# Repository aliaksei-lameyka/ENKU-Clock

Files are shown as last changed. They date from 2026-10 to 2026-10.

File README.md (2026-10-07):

# ENKU Clock

Open, repairable, local-first e-paper alarm clock.

ENKU Clock is a compact ambient clock built around an e-paper display, physical controls and a warm wake-light. It is designed to work without subscriptions, advertisements or a mandatory cloud service.

## Status

**Rev A hardware — PCBWay DFM / prototype review**

The Rev A electronics set contains four PCBs:

| Board | Size | Layers | Status |
|---|---:|---:|---|
| Mainboard | 88 × 48 mm | 4 | Rev A validated, prototype package submitted |
| Encoder board | 24 × 23 mm | 2 | Rev A validated |
| Snooze board | 26 × 18 mm | 2 | Rev A validated |
| Wake LED board | 78 × 8 mm | 2 | Rev A validated |

The current revision has passed native KiCad manufacturing checks with zero hard DRC violations and zero unconnected items before prototype submission.

## Rev A hardware

ENKU Clock Mainboard Rev A placement

ENKU Clock daughterboards Rev A placement

## Design goals

- local-first operation
- no subscription or mandatory cloud account
- e-paper primary display
- physical rotary control and Snooze button
- warm wake-light
- repairable distributed-board construction
- documented connectors and service access
- replaceable external modules where practical
- open hardware and firmware development

## System overview

```mermaid
flowchart LR
    USB[USB-C] --> MAIN[Mainboard<br/>ESP32-S3 + power + RTC + audio + E Ink]
    BAT[1S LiPo<br/>BAT + NTC] --> MAIN
    EINK[E Ink display] <-->|24-pin FPC| MAIN
    FL[Frontlight] <-->|6-pin FPC| MAIN
    ENC[Encoder board] <-->|5-wire harness| MAIN
    SNZ[Snooze board] <-->|3-wire harness| MAIN
    LED[Wake LED board] <-->|2-wire harness| MAIN
    SPK[Speaker] <-->|2-wire harness| MAIN
```

The distributed layout keeps user controls and lighting mechanically independent from the Mainboard, improving serviceability and enclosure freedom.

## Hardware

The system is split into four boards:

- **Mainboard** — ESP32-S3, USB-C, battery charging and power path, RTC, ambient-light sensor, audio, e-paper interface and lighting control.
- **Encoder board** — side rotary control.
- **Snooze board** — top physical Snooze control.
- **Wake LED board** — independent warm-light LED board.

### Mainboard highlights

- ESP32-S3-WROOM-1
- USB-C
- BQ24074 charger / dynamic power path
- TPS62840 3.3 V regulator
- RV-3028-C7 RTC
- VEML7700 ambient-light sensor
- MAX98357A I2S amplifier
- external E Ink booster/interface
- service connectors for distributed controls and lighting

## Repository layout

```text
hardware/
  mainboard/          Mainboard KiCad PCB and manufacturing data
  daughterboards/     Encoder, Snooze and Wake LED boards
  schematics/         Rev A schematic sources
  libraries/          Project KiCad symbols and footprints
  assembly/           BOM data
docs/
  README.md
  architecture.md
  connectors.md
  mechanical-interface.md
  manufacturing.md
  bringup.md
  release-checklist.md
  repairability.md
  status.md
.github/
  ISSUE_TEMPLATE/
  workflows/
```

## Manufacturing

Rev A is currently under PCBWay prototype DFM / sourcing review. Production files are generated from the checked KiCad sources rather than maintained as hand-edited manufacturing files.

For the Mainboard, the baseline fabrication target is:

- 4-layer FR-4
- 1.6 mm
- 1 oz outer / inner copper
- ENIG
- L2 continuous GND reference
- L3 power / utility distribution
- filled/capped via-in-pad where explicitly required for SMT assembly

See [docs/manufacturing.md](docs/manufacturing.md).

## Documentation

- [Documentation index](docs/README.md)
- [Architecture](docs/architecture.md)
- [Connectors and GPIO](docs/connectors.md)
- [Mechanical interface](docs/mechanical-interface.md)
- [External components & harness BOM](docs/external-components.md)
- [Rev A procurement plan — 5 prototypes](docs/procurement-reva.md)
- [Manufacturing](docs/manufacturing.md)
- [Rev A bring-up checklist](docs/bringup.md)
- [Release checklist](docs/release-checklist.md)
- [Repairability](docs/repairability.md)
- [Project status](docs/status.md)

## Repairability

ENKU Clock uses separate boards for controls and lighting so service parts can be replaced independently. Connectors, polarity and functional interfaces are documented wherever practical.

See [docs/repairability.md](docs/repairability.md).

## Firmware

Firmware will live in this repository as the Rev A bring-up stabilizes. The first firmware milestone is a hardware bring-up image covering power, USB, RTC, ambient-light sensing, controls, audio, E Ink and lighting.

## Project stage

This is prototype hardware. Files may still change after DFM review and physical Rev A validation.

## License

The project is intended to be open source. Final hardware/firmware license files will be added before the first tagged public release.

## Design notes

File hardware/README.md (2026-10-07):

# Hardware

This directory contains the canonical ENKU Clock Rev A hardware source.

- `mainboard/` — 4-layer Mainboard PCB
- `daughterboards/` — Encoder, Snooze and Wake LED PCBs
- `schematics/` — hierarchical Rev A schematic sheets
- `libraries/` — project-specific KiCad libraries
- `assembly/` — assembly BOM data
- `footprint-plan.csv` — footprint planning reference

Generated Gerbers and production archives are release artifacts, not hand-maintained source files.

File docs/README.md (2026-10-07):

# ENKU Clock documentation

Start here if you are looking for a specific part of the project.

| Topic | Document |
|---|---|
| System overview | [Architecture](architecture.md) |
| GPIO and connectors | [Connectors and GPIO](connectors.md) |
| Mechanical interface | [Mechanical interface](mechanical-interface.md) |
| External parts / harnesses | [External components](external-components.md) |
| 5-unit Rev A shopping / preparation list | [Procurement plan](procurement-reva.md) |
| Fabrication / assembly | [Manufacturing](manufacturing.md) |
| First power-up | [Rev A bring-up](bringup.md) |
| Release gates | [Release checklist](release-checklist.md) |
| Service philosophy | [Repairability](repairability.md) |
| Current project state | [Status](status.md) |

## Rev A state

Rev A is a prototype revision currently in fabricator DFM / sourcing review. CAD validation is complete for the submitted source state; physical validation begins when assembled hardware arrives.

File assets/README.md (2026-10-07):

# Visual assets

Generated placement maps are derived from the current Rev A KiCad board coordinates. They are documentation aids, not substitutes for Gerber/DFM review.

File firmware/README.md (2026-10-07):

# Firmware

ENKU Clock firmware will be added here as Rev A hardware bring-up begins.

Planned first-stage bring-up covers power, USB, RTC, ambient-light sensing, audio, E Ink, physical controls and wake-light control.

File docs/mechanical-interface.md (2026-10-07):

# Mechanical interface

## Mainboard coordinate convention

For Rev A mechanical review:

- y = 0 mm — rear enclosure wall
- y = 48 mm — front / display side
- x = 0 mm — left side
- x = 88 mm — right side

## USB-C

The current USB-C connector is located near the rear-right area of the Mainboard and opens toward the rear wall.

The enclosure must provide:

- plug overmold clearance;
- insertion/removal clearance;
- no rib loading the connector shell;
- no standoff collision with shell anchors.

## ESP32 antenna

The antenna volume must remain free of:

- copper outside the module design intent;
- battery;
- speaker magnet;
- cable bundles;
- metal fasteners or enclosure metal.

The enclosure above the antenna should remain plastic.

## User controls

User-facing controls are mechanically carried by daughterboards:

- Encoder board — right wall
- Snooze board — below top key
- Wake LED board — bottom diffuser channel

The Mainboard should not carry encoder shaft or Snooze-button mechanical loads.

## Display and frontlight

E Ink and frontlight FPCs connect directly to the Mainboard.

Mechanical design should allow:

- acceptable bend radius;
- connector access during service;
- display/FPC disconnection before Mainboard removal.

## Service objective

Battery, speaker, Encoder board, Snooze board, Wake LED board, display and Mainboard should be individually replaceable without cutting wires or desoldering another mechanical module.

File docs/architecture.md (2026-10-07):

# Architecture

ENKU Clock Rev A uses a distributed-board architecture.

## Mainboard

The Mainboard contains the system controller and shared power / peripheral functions:

- ESP32-S3-WROOM-1
- USB-C
- battery charging and dynamic power path
- 3.3 V system regulator
- RTC
- ambient-light sensor
- I2S audio amplifier
- E Ink interface and external booster network
- frontlight / wake-light control
- service and daughterboard connectors

The board outline is 88 × 48 mm and uses four copper layers.

## Daughterboards

### Encoder board

A small side-mounted board carrying the physical rotary control interface.

### Snooze board

A dedicated top-button board so the Snooze control can be positioned independently from the Mainboard.

### Wake LED board

A long narrow lighting board used for the warm wake-light. Keeping it separate allows the optical and mechanical design to evolve without redesigning the Mainboard.

## Design principles

The distributed architecture is deliberate:

- controls can be replaced independently;
- connectors can be documented and serviced;
- mechanical placement is not tied to one large rigid PCB;
- lighting can be iterated separately;
- the Mainboard remains accessible for repair and debugging.

## Revision policy

Rev A is the first physical prototype revision. Electrical and mechanical changes after prototype bring-up will be captured as a new revision rather than silently changing released manufacturing data.

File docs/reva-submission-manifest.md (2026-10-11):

# ENKU Clock Rev A — PCBWay submission manifest

This bundle is the authoritative **prototype submission package** for the source commit recorded at the bottom of the generated copy.

## Order split

| Folder | Board | Manufacturing route | Prototype qty | PCB spec |
|---|---|---|---:|---|
| `01-mainboard-PCBA` | Mainboard | PCBWay PCB + SMT assembly | 5 | 88 × 48 mm, 4-layer, 1.6 mm, ENIG, 1 oz outer/inner |
| `02-encoder-PCBA` | Encoder | PCBWay PCB + SMT assembly | 5 | 24 × 23 mm, 2-layer, 1.6 mm, ENIG |
| `03-snooze-PCBA` | Snooze | PCBWay PCB + SMT assembly | 5 | 26 × 18 mm, 2-layer, 1.6 mm, ENIG |
| `04-wake-led-BARE-PCB` | Wake LED | **Bare PCB only; local assembly** | 5 minimum | 78 × 8 mm, 2-layer, 1.0 mm, ENIG |

If PCBWay's price difference is negligible, ordering 10 bare Wake LED PCBs is acceptable for prototype spares, but the required functional set is five.

## What to upload to PCBWay

### Mainboard

Upload:
- `mainboard-reva-PCBWay-Gerbers.zip`
- `mainboard-reva-bom.csv`
- `mainboard-reva-cpl.csv`

Request **5 assembled boards**, top-side SMT assembly.

This submission **replaces** the old Mainboard inquiry/order package. Do not pay the old quotation without replacing its files and receiving a new sourcing review.

### Encoder

Upload:
- `encoder-board-reva-PCBWay-Gerbers.zip`
- `encoder-board-reva-bom.csv`
- `encoder-board-reva-cpl.csv`

Request **5 assembled boards**.

### Snooze

Upload:
- `snooze-board-reva-PCBWay-Gerbers.zip`
- `snooze-board-reva-bom.csv`
- `snooze-board-reva-cpl.csv`

Request **5 assembled boards**.

### Wake LED

Upload **only**:
- `wake-led-board-reva-BARE-PCB-Gerbers.zip`

Order as **bare PCB, no PCBWay assembly**.

The exact Nichia LEDs are sourced separately and assembled locally. The `local-assembly/` directory contains the BOM, CPL and top-paste Gerber for local stencil/reflow work.

## Mandatory sourcing instructions for PCBWay

PCBWay must provide the new **Actual Purchase Mfg Part #** list before payment.

Critical locks:

- J5: Molex **54550-2472**, 24-pin 0.5 mm TOP-CONTACT. No arbitrary substitute.
- J6 production target: Molex **54550-0672**. Rev A prototype alternate explicitly allowed: genuine Molex **54550-0671**. If neither genuine part is available, **DNP J6** and hand-fit locally.
- U5: Vishay **VEML7700-TR**. Do not silently substitute VEML7700-TT or an unverified -TR1 order code.
- Q_FL / Q2: AOS **AO3400A**. Any suffix/equivalent requires engineering approval.
- J8: JST **SM02B-GHS-TB(LF)(SN)**.
- U6 MAX98357A no longer requires a via-in-pad fill/cap process; the thermal pad exits to an adjacent normal GND via.

See `PCBWAY-SOURCING-GATES.md` for the complete sourcing audit.

## Wake LED local assembly

Exact Rev A LED:
**Nichia NFSW757GT-V3 sm275/P11d21-P12d22/K22-L12/R8000**, 2700 K, CRI80.

For five clocks:
- fitted: 30 LEDs;
- buy: **40 LEDs from one lot**;
- 10 remain as same-bin spares.

Polarity:
- pad 1 = cathode / K / WAKE_LED_RETURN;
- pad 2 = anode / A / resistor / +3V3.

Use controlled solder-paste deposition and a single reflow pass.

## Pre-payment gate

Before paying PCBWay:

1. DFM accepted for all three PCBA boards and the bare Wake LED PCB.
2. PCBWay returns the **new** Mainboard/Encoder/Snooze sourcing list against these exact BOMs.
3. Every substitution is compared against `PCBWAY-SOURCING-GATES.md`.
4. J6 is either exact 54550-0672, approved genuine 54550-0671, or explicitly DNP.
5. No Wake LED PCBA assembly is included in the PCBWay order.
6. Gerber/BOM/CPL files all come from the same generated submission bundle.

## Bring-up note

Physical panel fit remains part of prototype bring-up. The GDEY037T03-FL21 FPC contact-side geometry and the selected Molex 54550-series top-contact connector geometry have been audited and are no longer considered a PCB-release blocker.

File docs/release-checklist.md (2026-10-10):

# Release checklist

A hardware release is considered manufacturing-ready only when the checked source revision and generated manufacturing package agree.

## Source

- [x] Mainboard PCB source present
- [x] Encoder PCB source present
- [x] Snooze PCB source present
- [x] Wake LED PCB source present
- [x] project-specific footprints included
- [x] schematic sheets included
- [x] assembly BOM data included

## Rev A validation before first prototype

- [x] Mainboard native KiCad hard DRC passed
- [x] Mainboard unconnected count reached zero
- [x] Mainboard final production export passed
- [x] four copper layers exported
- [x] front and back solder mask exported
- [x] board outline and drill exported
- [x] BOM / CPL reference cross-check passed
- [x] daughterboard production artifacts generated
- [ ] current audited prototype package submitted for fabricator review
  - Previous PCBWay upload predates the final SI1308EDL, BQ24074, USB-C, EPD BOM and remote-input conditioning corrections and must be replaced before payment.

## Still required before calling Rev A physically validated

- [ ] fabricator DFM accepted
- [ ] exact sourced parts accepted
- [ ] assembled prototype received
- [ ] visual assembly inspection
- [ ] power bring-up completed
- [ ] USB validated
- [ ] RTC and ALS validated
- [ ] controls validated
- [ ] audio validated
- [ ] wake light validated
- [ ] frontlight validated
- [ ] E Ink validated
- [ ] sleep current measured
- [ ] enclosure fit verified
- [ ] Rev A issue log reviewed

## Release policy

Generated Gerbers, drill files, CPL and release ZIPs must come from a known source revision. Do not hand-edit generated fabrication output and then treat it as canonical source.

## Current audited manufacturing snapshot

Current green release-candidate source: **ed9ddd1** (`fix(bom): lock Rev A sourcing-critical part numbers`). Hardware geometry baseline: **1c3d2e55**.

- Mainboard source DRC: **0 violations / 0 unconnected**
- Daughterboards: **0 violations / 0 unconnected**
- Mainboard BOM ↔ CPL: **78 / 78 references, no missing or extra refs**
- Mainboard ↔ daughterboard harness audit: Encoder **5/5**, Snooze **3/3**, Wake LED **2/2** pin meanings match exactly for straight-through cables.
- Remote controls now have populated 10 kΩ external pull-ups on ENC_A / ENC_B / ENC_SW / SNOOZE_SW; Snooze also has a populated 10 nF hardware filter. Encoder RC capacitors remain omitted and debounce stays in firmware.
- USB-C J1 is now oriented with its mating face at the board edge; no J1 via-in-pad remains.
- U6 MAX98357A via-in-pad has been eliminated. The exposed pad remains on solid top-layer GND copper and exits to a normal adjacent GND through-via outside the thermal pad, so no special filled/capped via-in-pad process is required for U6.
- J5/J6 are locked to Molex 54550-2472 / 54550-0672 TOP-CONTACT parts. Exact GDEY037T03-FL21 front/back product imagery shows exposed gold contacts on the display-front side for both 24-pin and 6-pin tails, with black stiffeners on the reverse. With the intended fold toward the Mainboard F.Cu side this mates correctly to the Molex upper-contact geometry. The Molex recommended PCB pattern also matches the current footprints. Physical sample fit remains a bring-up check, not a PCB-release blocker.
- Exact GDEY037T03-FL21 reference-circuit audit: MBR0530 diode class, SI1308EDL MOSFET class, 10 uH / 3.0 x 3.0 x 1.5 mm EPD inductor class, and >=25 V X5R/X7R HV capacitor requirements are matched. Current HV capacitors are 50 V.
- L_EPD is now locked to Wurth 74438335100 (10 uH, 3.0 x 3.0 x 1.5 mm, 1.25 A rated, 2 A saturation class) with the manufacturer land pattern embedded in the PCB.
- GDEY037T03-FL21 / UC8253 BUSY is active-low during controller activity; firmware bring-up must use this polarity.
- Wake LED D1-D6 electrical polarity is pad 2 = anode / resistor / +3V3, pad 1 = cathode / WAKE_LED_RETURN. The cathode silkscreen marker is corrected and the accidental one-off D3 backside mask opening is removed.
- PCBWay sourcing gates are tracked in `docs/pcbway-sourcing-reva.md`: J6 has a genuine 54550-0671 Rev A fallback / DNP path; Wake LEDs are locked to stocked Nichia NFSW757GT-V3 R8000 2700 K (LEDRise SKU 33465) for local fit; VEML7700 is locked to -TR; AO3400A substitutions require explicit approval.
- Do not pay or release the existing PCBWay Mainboard order until the Gerber, BOM and CPL are replaced by the current audited set and PCBWay re-runs DFM/assembly review.

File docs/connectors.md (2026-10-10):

# Connectors and GPIO

This document captures the Rev A service interfaces and MCU ownership used by the current hardware.

## Internal architecture

The Clock is built around one Mainboard and three daughterboards:

| Interface | Remote module / load | Signals |
|---|---|---|
| Encoder | Encoder board | GND, ENC_A, ENC_B, ENC_SW, GND |
| Snooze | Snooze board | GND, SNOOZE_SW, GND |
| Wake light | Wake LED board | LED+, LED_RETURN_PWM |
| Battery | 1S LiPo pack | BAT+, BAT-, NTC |
| Speaker | speaker | SPK+, SPK- |
| E Ink | display FPC | 24-pin display interface |
| Frontlight | display/frontlight FPC | 6-pin frontlight interface |

Connector reference designators and final mating-part details should be verified against the physical Rev A assembly before a service manual is frozen.

## Encoder connector

Recommended logical order:

1. GND
2. ENC_A
3. ENC_B
4. ENC_SW
5. GND

Grounds on both cable edges are intentional. Rev A populates 10 kΩ external pull-ups on ENC_A / ENC_B / ENC_SW. Firmware should still debounce the mechanical encoder in software; no encoder RC capacitors are populated.

## Snooze connector

1. GND
2. SNOOZE_SW
3. GND

The dual-ground arrangement is intentional. Rev A populates a 10 kΩ external pull-up and 10 nF shunt capacitor on SNOOZE_SW, giving a 100 µs hardware RC time constant for EMI suppression and clean wake-state bias.

## Wake-light connector

1. LED+
2. LED_RETURN_PWM

PWM/current switching remains on the Mainboard.

## Battery connector

1. BAT+
2. BAT-
3. NTC

The target battery is a protected 1S LiPo with an integrated NTC where practical.

## Speaker connector

1. SPK+
2. SPK-

A short twisted pair is preferred if the final harness length requires it.

## USB

ESP32-S3 native USB is reserved for:

| Function | GPIO |
|---|---:|
| USB D- | GPIO19 |
| USB D+ | GPIO20 |

GPIO19/20 are not shared with other functions.

## Rev A GPIO map

### Wake and user input

| Function | GPIO |
|---|---:|
| BAT_ADC | GPIO1 |
| RTC_INT | GPIO4 |
| SNOOZE_SW | GPIO5 |
| ENC_A | GPIO6 |
| ENC_B | GPIO7 |
| ENC_SW | GPIO8 |

GPIO0 and GPIO3 are deliberately avoided for user controls because of strapping roles. GPIO2 is currently unallocated; the former BAT_ADC_EN function was removed because the battery divider is intentionally always-on.

### I2C

| Function | GPIO |
|---|---:|
| I2C_SDA | GPIO9 |
| I2C_SCL | GPIO10 |

Current shared devices include the RTC and ambient-light sensor.

### E Ink

| Function | GPIO |
|---|---:|
| EPD_SCK | GPIO11 |
| EPD_MOSI | GPIO12 |
| EPD_CS | GPIO13 |
| EPD_DC | GPIO14 |
| EPD_RST | GPIO15 |
| EPD_BUSY | GPIO16 |

### Lighting

| Function | GPIO |
|---|---:|
| WAKE_LED_PWM | GPIO17 |
| FRONTLIGHT_PWM | GPIO18 |

### Audio

| Function | GPIO |
|---|---:|
| I2S_BCLK | GPIO35 |
| I2S_LRCLK | GPIO36 |
| I2S_DOUT | GPIO37 |
| AMP_SD | GPIO38 |

### Charger / power status

| Function | GPIO |
|---|---:|
| CHG_STATUS | GPIO47 |
| POWER_GOOD | GPIO48 |

## Debug interfaces

The Rev A map preserves:

- GPIO39–42 for JTAG/debug
- GPIO43/44 for UART0
- BOOT access on GPIO0
- EN / CHIP_PU reset access

## Wake behavior

Mandatory deep-sleep wake sources:

- RTC_INT
- SNOOZE_SW

Optional:

- ENC_SW

Quadrature rotation itself is not required to wake the device in the first firmware revision.

## Harness rules

- no harness across the ESP32 antenna volume;
- no harness through the encoder shaft sweep;
- speaker wiring should stay away from the encoder bundle where practical;
- wake-light PWM return should not share a long thin return path with encoder signals;
- battery wiring should remain short and mechanically protected.

## Pre-production contact-side gate

- J5 uses Molex 54550-2472. Molex classifies 54550-series **72** tape-pack variants as right-angle ZIF **top-contact** connectors. Exact FL21 front/back product imagery shows the 24-pin tail contacts on the display-front side and a stiffener on the reverse; the intended fold toward the Mainboard leaves the contacts on the upper side for J5.
- J6 uses Molex 54550-0672, likewise a **top-contact** 0.5 mm ZIF connector. Exact FL21 product imagery shows the 6-pin frontlight tail has the same front-side exposed-contact / reverse-side stiffener arrangement. The Molex drawing explicitly places the contact point on the upper side of the inserted FPC, matching the intended fold. Do not approve an arbitrary substitute; replacement must preserve contact side, 0.5 mm pitch, pin count, pad pattern, insertion direction, actuator envelope, and mating FPC thickness.
- If the production display/frontlight FPC presents contacts on the opposite side, change the connector family or mechanical orientation before PCB release; do not solve this by flipping logical pin numbering.

## Straight-through harness audit

The current Rev A PCB sources were compared pin-by-pin. The internal harnesses are intentionally straight-through and the logical meaning of each pin matches at both board ends:

| Harness | Mainboard | Daughterboard | Result |
|---|---|---|---|
| Encoder | J3: 1 GND, 2 ENC_A, 3 ENC_B, 4 ENC_SW, 5 GND | J1: same order | PASS |
| Snooze | J4: 1 GND, 2 SNOOZE_SW, 3 GND | J1: same order | PASS |
| Wake LED | J8: 1 +3V3, 2 WAKE_LED_RETURN | J1: same order | PASS |

Do not use a cable assembly that reverses conductor order end-to-end. Pin numbering, not visual wire position, is authoritative.

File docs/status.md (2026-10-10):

# Project status

## Rev A

**Hardware:** an earlier prototype package was submitted for DFM / assembly review, but the audited Mainboard source has since advanced. The current package must replace the earlier PCBWay upload before payment.

### Mainboard

- PCB source: complete for Rev A submission
- native KiCad hard DRC: pass
- unconnected items: 0 at final production gate
- four-layer fabrication package: generated successfully
- BOM / CPL cross-check: pass, **78 / 78 references**
- daughterboard harness map: pass, straight-through pin meanings match for Encoder / Snooze / Wake LED
- remote controls: 10 kΩ external pull-ups populated on encoder A/B/SW and Snooze; Snooze also has 10 nF hardware filtering
- MAX98357A exposed-pad via-in-pad removed; EP exits to adjacent GND via outside the pad
- sourcing BOM locked for VEML7700-TR, AO3400A and exact JST/Molex connector MPNs
- physical bring-up: pending fabricated hardware

### Encoder board

- Rev A PCB source complete
- fabrication / assembly package submitted
- physical validation pending

### Snooze board

- Rev A PCB source complete
- fabrication / assembly package submitted
- physical validation pending

### Wake LED board

- Rev A PCB source complete
- LED cathode assembly marker corrected; accidental one-off backside mask opening removed
- current source supersedes the previously submitted fabrication / assembly package and must be re-exported before manufacture
- exact Nichia NFSW757G-V3 2700 K sourcing remains open because PCBWay reported it out of stock
- physical validation pending

## Next milestones

1. Fabricator DFM / sourcing review
2. Rev A fabrication and assembly
3. Power-rail and USB bring-up
4. RTC / sensor / audio validation
5. E Ink power and waveform bring-up
6. Daughterboard validation
7. Wake-light optical test
8. Rev A issue log
9. Rev B decision

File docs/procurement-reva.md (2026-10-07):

# Rev A procurement list — 5 prototype Clocks

Scope: parts and materials required to turn the PCBWay Rev A board set into **five complete ENKU Clock prototypes**.

Planning rule:
- five complete units are the build target;
- buy or prepare **one practical spare** for fragile / failure-prone / supplier-dependent external parts;
- board-side PCBA parts are excluded because they are handled in the PCBWay assembly orders.

## 1. External electronic parts

| Item | Per Clock | Build qty (5) | Recommended order qty | Status | Notes |
|---|---:|---:|---:|---|---|
| Good Display GDEY037T03-FL21, warm frontlight | 1 | 5 | **6** | ORDER | One spare display for FPC/mechanical/bring-up risk |
| PUI Audio AS04004PR-R, 4 Ω / 3 W | 1 | 5 | **6** | ORDER | One spare for acoustic/mechanical testing |
| Protected 605080 3000 mAh 1S LiPo + 10 kΩ NTC | 1 | 5 | **6** | ORDER / VERIFY | Prefer 3-wire JST-PH 2.0 terminated pack |
| Encoder harness, JST-GH 5p | 1 | 5 | **6** | MAKE / ORDER | 70–100 mm target; final length from enclosure |
| Snooze harness, JST-GH 3p | 1 | 5 | **6** | MAKE / ORDER | 60–90 mm target |
| Wake LED harness, JST-GH 2p | 1 | 5 | **6** | MAKE / ORDER | 40–70 mm target |
| Speaker harness, JST-PH 2p | 1 | 5 | **6** | MAKE / ORDER | 60–120 mm target |
| Battery harness, JST-PH 3p | 1 | 5 | **6** | MAY COME WITH BATTERY | Avoid duplicate if battery supplier terminates pack |

### Display purchasing note

Order the **frontlight version** of GDEY037T03-FL21 and explicitly request:
- warm-white frontlight;
- confirmation of frontlight CCT / available warm bin;
- 24-pin FPC contact orientation;
- 6-pin frontlight FPC contact orientation and conductor order.

Do not substitute a non-frontlight GDEY037T03 variant.

## 2. Connector housings and contacts

If harnesses are not purchased pre-crimped, procure:

| Part | Use | Needed contacts/housings for 5 | Recommended order qty |
|---|---|---:|---:|
| JST GHR-05V-S | Encoder harness housing | 5 | **6 housings** |
| JST GHR-03V-S | Snooze harness housing | 5 | **6 housings** |
| JST GHR-02V-S | Wake LED harness housing | 5 | **6 housings** |
| JST PHR-2 | Speaker harness housing | 5 | **6 housings** |
| JST PHR-3 | Battery harness housing | 5 | **6 housings** |
| JST SSHL-002T-P0.2 | GH crimp contacts | 50 total contacts for 5 systems if both ends are crimped | **60–70 contacts** |
| JST SPH-002T-P0.5S | PH crimp contacts | 25 total contacts for 5 systems if both ends are crimped | **30–40 contacts** |

Contact counts depend on whether the remote side is terminated directly to the part, uses a board-side GH/PH connector, or arrives as a vendor harness. Prefer pre-crimped leads for the Rev A build if a reliable source is available.

## 3. 3D-printed parts

| Printed part | Per Clock | Build qty | Recommended print qty | Status |
|---|---:|---:|---:|---|
| Main enclosure set | 1 | 5 | **5 + one service/test shell as needed** | CAD / PRINT |
| Encoder knob | 1 | 5 | **7** | PRINT | Two extra because fit/tolerance tuning is likely |
| Snooze key / cap | 1 | 5 | **7** | PRINT / TUNE | Two extra for travel/feel experiments |
| Internal supports / brackets | as CAD | 5 sets | **5 sets + test pieces** | CAD / PRINT |
| Wake-light diffuser carrier | 1 | 5 | **6** | CAD / PRINT | Diffuser material itself listed separately |

### Encoder knob

The knob is an ENKU-designed **3D-printed part**.

Rev A fit gate:
- shaft fit on ALPS EC11E15244G1;
- no wobble;
- no rubbing against side wall;
- enough pull-off resistance for normal use;
- still removable for service.

Print at least two extra knobs in the first tolerance run.

## 4. Optical / acoustic / mechanical consumables

| Item | Per Clock | Build qty | Recommended order qty | Status |
|---|---:|---:|---:|---|
| Wake-light diffuser material | 1 cut piece | 5 | material for **8–10 pieces** | SELECT |
| Speaker acoustic gasket / foam | 1 | 5 | **6–10** | SELECT |
| Display perimeter foam / protective gasket | 1 | 5 | **6** | SELECT |
| Battery retention foam / removable pad | as needed | 5 | one sheet / roll | SELECT |
| Cable retention clips / printed channels | as CAD | 5 sets | print with enclosure | CAD |

No permanent adhesive should make the battery non-serviceable.

## 5. Fasteners

Exact screw lengths remain dependent on enclosure CAD, but plan around the existing M2 board mounting strategy.

Prototype stock to have on hand:

| Fastener | Suggested prototype stock |
|---|---:|
| M2 machine screws, short lengths around 4/6/8 mm | **20–30 each useful length** |
| M2 washers | **30** |
| M2 nuts | **20** |
| M2 heat-set inserts, if used after shell testing | **20–30** |

Do not bulk-order final screws until enclosure wall/standoff dimensions are frozen.

## 6. Already covered by PCBWay PCBA

Do **not** buy these separately for the five prototype units unless PCBWay flags sourcing problems:

- ESP32-S3 module;
- BQ24074;
- TPS62840;
- RV-3028-C7;
- VEML7700;
- MAX98357A;
- USB-C and USB ESD;
- all Mainboard passives / E Ink booster parts;
- board-side JST/FPC connectors;
- Encoder EC11E15244G1;
- Snooze KSC221GLFS;
- six Nichia 2700 K LEDs per Wake LED board;
- Wake LED resistors;
- all four fabricated/assembled PCB types.

PCBWay sourcing must still be reviewed before payment because the Mainboard BOM may require exact-MPN clarification.

## 7. Bench / bring-up items

Not product BOM, but required to validate Rev A efficiently:

- USB-C data/power cable known to support data;
- current-limited bench supply;
- USB power meter;
- multimeter;
- oscilloscope / logic analyzer where available;
- fine probes / grabbers;
- spare mating JST leads;
- ESD-safe tweezers;
- Kapton tape;
- flux and fine solder for rework;
- small-gauge silicone wire;
- heat-shrink assortment.

## 8. Buy-now vs wait

### Safe to source now

- **6 × GDEY037T03-FL21 warm-frontlight displays**, after supplier confirms exact frontlight option;
- **6 × AS04004PR-R speakers**;
- **6 × 605080-class batteries** only if connector polarity, 10 kΩ NTC and pack dimensions are confirmed;
- small quantities of JST housings/contacts or pre-crimped leads;
- general M2 prototype hardware.

### Wait for enclosure CAD / PCBWay audit

- final harness lengths;
- production battery wire length;
- final fastener lengths;
- diffuser geometry/material cut dimensions;
- enclosure production quantity;
- any PCB parts PCBWay asks to substitute.

## 9. Minimum Rev A completeness check

Before calling one prototype mechanically complete, one full unit must have:

- [ ] Mainboard
- [ ] Encoder board
- [ ] Snooze board
- [ ] Wake LED board
- [ ] GDEY037T03-FL21 warm-frontlight display
- [ ] AS04004PR-R speaker
- [ ] 605080-class battery with NTC
- [ ] all five internal harnesses / mating connections
- [ ] printed enclosure
- [ ] printed encoder knob
- [ ] printed Snooze key
- [ ] wake-light diffuser
- [ ] service fasteners

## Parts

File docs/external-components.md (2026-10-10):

# External components — Rev A prototype

This list covers parts required for a complete ENKU Clock prototype that are **not part of the assembled PCB BOM**.

## Status legend

- **LOCK** — selected for Rev A prototype
- **LOCK / VERIFY** — selected, but physical sample or supplier detail must be verified before production
- **OPEN** — still needs final mechanical/supplier decision

## Core external parts

| Function | Selected part / target | Status | Notes |
|---|---|---|---|
| E Ink display + frontlight | Good Display **GDEY037T03-FL21** | LOCK / VERIFY | 3.7", 416×240, UC8253, 24-pin 0.5 mm E Ink FPC + bonded 6-pin frontlight FPC |
| Display frontlight color | Warm white | LOCK / VERIFY | Specify warm-white option in supplier RFQ; confirm exact CCT/bin on sample |
| Speaker | PUI Audio **AS04004PR-R** | LOCK / VERIFY | 40 mm round, 4 Ω, 3 W rated, 4 W max; acoustic/enclosure test required |
| Battery prototype | YDL **605080 3000 mAh** or equivalent custom pack | LOCK / VERIFY | Protected 1S LiPo, target 3-wire JST-PH 2.0 with 10 kΩ NTC |
| Enclosure | ENKU Clock printed enclosure | OPEN | Final Rev A CAD / fit validation |
| Encoder knob | Custom ENKU 3D-printed knob | LOCK / PRINT | Printed part; must fit EC11E15244G1 shaft and enclosure |
| Snooze key/cap | Custom ENKU top key | OPEN | Mechanical force/travel tuning after prototype |
| Wake-light diffuser | Custom diffuser/light pipe | OPEN | Optical test with six 2700 K LEDs |
| Fasteners | M2 service screws / inserts as required | OPEN | Freeze with enclosure CAD |

## Display

### Selected module

**Good Display GDEY037T03-FL21**

Rev A electrical interface is already designed for this display family.

Key requirements to verify on the physical sample before production:

1. physical confirmation that the production sample matches the currently documented front-side exposed-contact orientation for both FPC tails;
2. frontlight conductor order;
3. warm-white LED option / requested CCT;
4. mechanical outline and FPC exit relative to enclosure CAD.

The bonded frontlight should be purchased as part of the complete display assembly; it is not treated as a separate ENKU-installed optical layer.

## Speaker

### Rev A prototype selection

**PUI Audio AS04004PR-R**

Target characteristics:
- 40 mm diameter
- 4 Ω
- 3 W rated
- 4 W maximum
- approximately 86 dB sensitivity
- approximately 17.5 mm seated height

The Mainboard already includes:
- MAX98357A I²S amplifier;
- SYS_RAW amplifier power;
- J7 2-pin speaker connector;
- SPK+ / SPK- differential output.

The speaker itself is external and therefore does not appear in the Mainboard assembly BOM.

Prototype gate:
- enclosure fit;
- acoustic chamber;
- alarm SPL;
- distortion at useful volume;
- vibration/rattle;
- current consumption.

## Battery

### Rev A prototype target

**605080-class, 3000 mAh, protected 1S LiPo**

Preferred prototype implementation:
- 3.7 V nominal;
- protection PCB;
- 10 kΩ NTC;
- three-wire connection;
- JST-PH 2.0 mating interface;
- target pack envelope around 6 × 50 × 82 mm before service clearance.

Battery polarity must be verified against the actual harness before connection.

## Harnesses and mating connectors

The PCB BOM contains the **board-side connectors**. A complete Clock also needs mating housings, contacts and wire harnesses.

### JST GH — daughterboards

| Harness | Board-side | Mating housing | Circuits |
|---|---|---|---:|
| Encoder | SM05B-GHS-TB | GHR-05V-S | 5 |
| Snooze | SM03B-GHS-TB | GHR-03V-S | 3 |
| Wake LED | SM02B-GHS-TB | GHR-02V-S | 2 |

Crimp contact family: **SSHL-002T-P0.2**.

### JST PH — battery / speaker

| Harness | Board-side | Mating housing | Circuits |
|---|---|---|---:|
| Battery | 3-pin PH header | PHR-3 | 3 |
| Speaker | 2-pin PH header | PHR-2 | 2 |

Crimp contact baseline: **SPH-002T-P0.5S** where wire gauge is compatible.

Final wire gauge, length and pre-crimp supplier should be frozen with enclosure routing.

## Parts already included on PCBs

The following are **not missing external parts** because they are already included in the PCB assembly data:

- ESP32-S3 module
- BQ24074 charger / power path
- TPS62840 regulator
- RV-3028-C7 RTC
- VEML7700 ambient-light sensor
- MAX98357A audio amplifier
- USB-C connector and USB ESD
- E Ink board-side FPC connector
- frontlight board-side FPC connector
- battery / speaker board-side connectors
- encoder / Snooze / Wake LED board-side connectors
- Encoder EC11E15244G1
- Snooze KSC221GLFS
- six Nichia **NFSW757GT-V3 sm275/P11d21-P12d22/K22-L12/R8000** 2700 K CRI80 wake LEDs
- Wake LED current-setting resistors

## Procurement gate before final assembly

Before closing the Rev A prototype kit, confirm that the following physically exist in hand:

- [ ] 1 × GDEY037T03-FL21 per Clock
- [ ] 1 × AS04004PR-R speaker per Clock
- [ ] 1 × protected 605080-class battery with 10 kΩ NTC per Clock
- [ ] Encoder GH 5-pin harness
- [ ] Snooze GH 3-pin harness
- [ ] Wake LED GH 2-pin harness
- [ ] Speaker PH 2-pin harness
- [ ] battery PH 3-pin harness / correctly terminated pack
- [ ] 3D-printed encoder knob
- [ ] Snooze key/cap
- [ ] wake-light diffuser
- [ ] enclosure + service fasteners

## Production note

Rev A external selections are prototype locks, not automatic production locks. Speaker, battery, harness supplier and optical parts must be validated in the assembled enclosure before volume sourcing.

## Wake LED prototype sourcing

Rev A uses the exact Nichia **NFSW757GT-V3 R8000 2700 K** bin recorded in the Wake LED BOM. A current European prototype source is LEDRise/Lumitronix SKU **33465**.

For five clocks:
- fitted quantity: 30 LEDs;
- preferred purchase: **40 LEDs** from one lot;
- sourcing snapshot: EUR 0.17 each, so 40 LEDs are about **EUR 6.80** before shipping/tax.

Because the Wake LED board contains only one JST connector, six resistors and six LEDs, local single-pass reflow of the whole board is preferred over paying a separate PCBA setup merely to work around PCBWay's unavailable Nichia stock. A stencil / controlled paste deposit is preferred to iron-soldering the LEDs.

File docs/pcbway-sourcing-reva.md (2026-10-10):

# PCBWay sourcing audit — Rev A

This file records sourcing decisions that must be checked against PCBWay's **new** quotation before payment. The October 10, 2026 quotations were generated from older Rev A files and are not release authority for the current hardware.

## Old quotation references

| Board | PCBWay product / inquiry | Result from old quote |
|---|---|---|
| Mainboard | T-1M2W1167728A | Questions present; BOM is now stale and must be replaced |
| Encoder | T-2Y4W1167728A | Exact EC11E15244G1 and JST SM05B-GHS-TB(LF)(SN) appeared; no unresolved question found |
| Snooze | T-2Y6W1167728A | Exact KSC221GLFS and JST SM03B-GHS-TB(LF)(SN) appeared; no unresolved question found |
| Wake LED | T-2Y8W1167728A | Nichia NFSW757G-V3 reported out of stock |

## Hard sourcing gates

### J5 — display FPC

- Required: **Molex 54550-2472**
- 24 circuits, 0.5 mm pitch, 1.2 mm height, right-angle SMT ZIF, **TOP CONTACT**
- Do not substitute a 54548-series or bottom-contact connector.
- Any alternate manufacturer must be approved against contact side, pad pattern, FPC thickness, insertion direction, actuator envelope and pin-1 orientation.

### J6 — frontlight FPC

- Required: **Molex 54550-0672**
- 6 circuits, 0.5 mm pitch, 1.2 mm height, right-angle SMT ZIF, **TOP CONTACT**
- PCBWay's old quote explicitly reported this part **out of stock**.
- **Rev A prototype alternate approved:** genuine **Molex 54550-0671**. It is obsolete for new production, but it has the same 6-position / 0.5 mm / 1.2 mm / right-angle / top-contact interface and the same recommended PCB land pattern; Molex/DigiKey list 54550-0672 as the manufacturer-recommended replacement for 54550-0671.
- Production remains locked to **54550-0672**.
- If PCBWay cannot source either genuine Molex part, populate J6 as **DNP** and hand-fit a genuine 54550-0671 or 54550-0672 locally.
- Do **not** accept Würth 687106149022 as a drop-in: despite being surfaced by some distributor substitution tools, it is bottom-contact and 2.2 mm high.
- No other substitute is approved.

### J8 — Wake LED harness

- Required: **JST SM02B-GHS-TB(LF)(SN)**
- PCBWay's old Mainboard quote asked for an exact part number / component URL. The BOM now carries the exact JST MPN.
- The Wake LED daughterboard uses the same connector family/order and must remain a 1:1 harness.

### U5 — ambient-light sensor

- Required: **Vishay VEML7700-TR**
- The Rev A mechanical implementation uses the side-view VEML7700 package.
- PCBWay's old quote contained a `VEML7700-TR1` string. That suffix is **not approved** for Rev A unless PCBWay provides a manufacturer datasheet/order-code trace proving equivalence.
- `VEML7700-TT` is the top-view variant and is not an approved mechanical substitute.

### Q_FL / Q2 — lighting MOSFETs

- Required prototype part: **Alpha & Omega Semiconductor AO3400A**
- SOT-23, 30 V N-channel MOSFET; current PCB pinout assumes the AO3400A pinout.
- PCBWay's old quote contained an `AO3400AQ` string. Do not approve that string or another suffix/equivalent without the exact manufacturer, datasheet, pinout and low-VGS RDS(on) review.

### Wake LED D1-D6

- Rev A prototype is now locked to **Nichia NFSW757GT-V3 sm275/P11d21-P12d22/K22-L12/R8000**, 2700 K, CRI80, 3 x 3 x 0.65 mm.
- Distributor reference: **LEDRise SKU 33465**. The sourcing snapshot used for this lock showed stock in Germany (>1000 pcs) at EUR 0.17 each through the official Nichia distribution channel; availability and price must be rechecked at purchase time.
- PCBWay's old quote reported generic NFSW757G-V3 **out of stock**, therefore PCBWay should not substitute the LED.
- Preferred Rev A build method: order Wake LED PCBs bare (or DNP D1-D6) and fit the exact Nichia LEDs locally. For a five-clock batch, 30 LEDs are required; **40 pcs** is the preferred prototype buy to keep 10 spares from the same lot.
- Nichia **NFSW757G-P5V1** is a current recommended 757-series device and has the same nominal package size / recommended land-pattern dimensions, but its datasheet uses a different cathode-orientation rule from the V3 datasheet. It is therefore **not approved as a blind drop-in** on the Rev A footprint; using it requires a deliberate footprint/polarity ECO and validation.
- Nichia NFSW757G-V3 (Rs030) keeps the V3 package family but has substantially lower luminous flux and a special-color-rendering spectrum, so it is not the preferred Wake-light prototype part.
- Do not accept an arbitrary “3030 warm white” replacement.

## Items already acceptable in the old quote, subject to re-quote

The old quote showed the intended exact core parts or manufacturer families for ESP32-S3-WROOM-1-N8, BQ24074RGTR, TPS62840DLCR, RV-3028-C7, MAX98357AETE+T, USBLC6-2SC6, SI1308EDL-T1-GE3, the JST GH encoder/snooze connectors, and the quoted Samsung high-voltage capacitor choices.

These are **not blanket approvals**: the new quote must still be compared line-by-line with the current BOM because the Mainboard source and BOM have changed.

## Release rule

Do not pay the current/old PCBWay Mainboard quotation. Upload manufacturing outputs generated from the current green source, request a new Actual Purchase Mfg Part list, and approve substitutions only after this file and the BOM assembly notes agree with PCBWay's proposed exact MPNs.

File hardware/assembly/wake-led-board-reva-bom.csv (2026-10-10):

Designator | Qty | Manufacturer | MPN | Description | Footprint | Populate
J1 | 1 | JST | SM02B-GHS-TB(LF)(SN) | GH 1.25mm 2-pin right-angle SMD | JST_GH_SM02B-GHS-TB_1x02-1MP_P1.25mm_Horizontal | YES
D1 D2 D3 D4 D5 D6 | 6 | Nichia | NFSW757GT-V3 sm275/P11d21-P12d22/K22-L12/R8000 | 3030 warm-white LED 2700K CRI80; exact Rev A prototype bin; pad 1 = K/cathode = WAKE_LED_RETURN; distributor reference LEDRise SKU 33465; no P5-series substitution without footprint/polarity ECO | Nichia_NFSW757G_V3 | YES
R1 R2 R3 R4 R5 R6 | 6 | Generic | 56R 1% 0603 | 56 ohm current-setting resistor 0603 | R_0603_1608Metric | YES

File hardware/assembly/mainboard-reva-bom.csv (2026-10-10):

Designator | Quantity | Value | Footprint | Assembly note
C_ALS1,C_AUD1,C_MCU1,C_RTC,C10 | 5 | 100nF | Capacitor_SMD:C_0603_1608Metric
C_AUD2,C_MCU2,C5 | 3 | 10uF | Capacitor_SMD:C_0805_2012Metric
C_EN | 1 | 1uF | Capacitor_SMD:C_0603_1608Metric
C_SNZ | 1 | 10nF | Capacitor_SMD:C_0603_1608Metric | Snooze hardware debounce / EMI filter; populated in Rev A
C_IN | 1 | 1uF/10V | Capacitor_SMD:C_0603_1608Metric | Local BQ24074 IN bypass; place close to U2 IN/GND
C_EPDIN,C_PUMP | 2 | 4.7uF/50V | Capacitor_SMD:C_0805_2012Metric | GDEY037T03-FL21 reference requires X5R/X7R and >=25V; proposed Samsung CL21A475KBQNNNE is 4.7uF 50V X5R
C_MCU3 | 1 | 100uF low-ESR | Capacitor_SMD:C_1210_3225Metric
C_PREVGH,C_PREVGL,C_VCOM,C_VDD,C_VSH1,C_VSH2,C_VSL | 7 | 1uF/50V | Capacitor_SMD:C_0603_1608Metric | GDEY037T03-FL21 reference requires X5R/X7R and >=25V; proposed Samsung CL10B105KB8NQNC is 1uF 50V X7R
C1 | 1 | 1uF/10V | Capacitor_SMD:C_0603_1608Metric
C2 | 1 | 4.7uF SYS | Capacitor_SMD:C_0805_2012Metric
C3 | 1 | 4.7uF BAT | Capacitor_SMD:C_0805_2012Metric
C4 | 1 | 4.7uF | Capacitor_SMD:C_0805_2012Metric
D1,D2,D3 | 3 | MBR0530 | Diode_SMD:D_SOD-123
J1 | 1 | USB-C | ENKU_Clock:HRO-TYPE-C-31-M-12 | HRO TYPE-C-31-M-12 or footprint-compatible approved equivalent
J2 | 1 | BATTERY | Connector_JST:JST_PH_S3B-PH-K_1x03_P2.00mm_Horizontal | 3-wire 1S Li-ion/LiPo pack required; TEMP must be 10k NTC to PACK-/GND
J3 | 1 | SM05B-GHS-TB(LF)(SN) / ENCODER | Connector_JST:JST_GH_SM05B-GHS-TB_1x05-1MP_P1.25mm_Horizontal | Locked JST GH 5-pin right-angle; exact MPN SM05B-GHS-TB(LF)(SN)
J4 | 1 | SM03B-GHS-TB(LF)(SN) / SNOOZE | Connector_JST:JST_GH_SM03B-GHS-TB_1x03-1MP_P1.25mm_Horizontal | Locked JST GH 3-pin right-angle; exact MPN SM03B-GHS-TB(LF)(SN)
J5 | 1 | Molex 54550-2472 / GDEY037T03-FL21 | ENKU_Clock:Molex_54550_24P_0.5mm | LOCKED: Molex 54550-2472, 24-pin 0.5mm TOP-CONTACT ZIF. No 54548-series/bottom-contact or other substitute without engineering approval
J6 | 1 | Molex 54550-0672 / FL21 frontlight | ENKU_Clock:Molex_54550_6P_0.5mm | Production lock: Molex 54550-0672, 6-pin 0.5mm TOP-CONTACT ZIF. Rev A prototype alternate explicitly approved: genuine Molex 54550-0671 only; same top-contact geometry and manufacturer land pattern, with 0672 listed as Molex-recommended successor. FL21 pins 1-2 LED+, 3-4 NC, 5-6 LED-. If neither genuine part is available, populate J6 DNP and hand-fit later
J7 | 1 | SPEAKER | Connector_JST:JST_PH_S2B-PH-K_1x02_P2.00mm_Horizontal
J8 | 1 | SM02B-GHS-TB(LF)(SN) / WAKE_LED | Connector_JST:JST_GH_SM02B-GHS-TB_1x02-1MP_P1.25mm_Horizontal | Locked JST GH 2-pin right-angle; exact MPN SM02B-GHS-TB(LF)(SN)
L_EPD | 1 | 74438335100 10uH | ENKU_Clock:WE-MAPI_3015_74438335100 | Locked prototype MPN: Wurth 74438335100; 3.0x3.0x1.5mm, 1.25A rated, 2A Isat; land pattern matched to manufacturer recommendation
L1 | 1 | 2.2uH | Inductor_SMD:L_3.2x2.5mm_H1.2mm | Preferred prototype MPN: Delta/Cyntec VCTA32251B-2R2MS6
Q_EPD | 1 | SI1308EDL-T1-GE3 | Package_TO_SOT_SMD:SOT-323_SC-70
Q_FL | 1 | AO3400A / FRONTLIGHT | Package_TO_SOT_SMD:SOT-23 | LOCKED prototype part: Alpha & Omega Semiconductor AO3400A, SOT-23, 30V N-channel. Do not use AO3400AQ or another suffix/equivalent without datasheet and pinout approval
Q2 | 1 | AO3400A / WAKE | Package_TO_SOT_SMD:SOT-23 | LOCKED prototype part: Alpha & Omega Semiconductor AO3400A, SOT-23, 30V N-channel. Do not use AO3400AQ or another suffix/equivalent without datasheet and pinout approval
R_BOOT,R_CHG_PU,R_EN,R_ENCA,R_ENCB,R_ENCSW,R_INT,R_PG_PU,R_SNZ,R_VBACKUP | 10 | 10k | Resistor_SMD:R_0603_1608Metric | R_ENCA/R_ENCB/R_ENCSW/R_SNZ are external pull-ups for remote mechanical controls
R_SCL,R_SDA | 2 | 4.7k | Resistor_SMD:R_0603_1608Metric | I2C pull-ups; aligned with VEML7700 application guidance
R_FGATE,R_GATE | 2 | 47R | Resistor_SMD:R_0603_1608Metric
R_FLIM | 1 | 10R / tune | Resistor_SMD:R_0603_1608Metric | Rev A optical/current-limit starting value; confirm 10R before assembly
R_FPD,R_GPD | 2 | 100k | Resistor_SMD:R_0603_1608Metric
R_GDR | 1 | 10k 1% | Resistor_SMD:R_0603_1608Metric | EPD GDR gate pull-down; reference booster value
R10 | 1 | 1M 1% | Resistor_SMD:R_0603_1608Metric | Battery ADC upper divider resistor
R_ILIM | 1 | 1.18k | Resistor_SMD:R_0603_1608Metric | BQ24074 input current-limit programming resistor
R_ISET | 1 | 1.13k | Resistor_SMD:R_0603_1608Metric
R_RESE | 1 | 0.47R 1% | Resistor_SMD:R_0805_2012Metric
R_SD | 1 | 2.2k | Resistor_SMD:R_0603_1608Metric
R_TMR | 1 | 68k | Resistor_SMD:R_0603_1608Metric | BQ24074 safety timer ~9.1h typical; margin for ~3Ah battery in USB500 mode
R_USB_DM,R_USB_DP | 2 | 22R | Resistor_SMD:R_0603_1608Metric
R_VSET | 1 | 267k 1% | Resistor_SMD:R_0603_1608Metric
R1 | 1 | 5.1k CC1 | Resistor_SMD:R_0603_1608Metric
R2 | 1 | 5.1k CC2 | Resistor_SMD:R_0603_1608Metric
R11 | 1 | 330k 1% | Resistor_SMD:R_0603_1608Metric
U1 | 1 | ESP32-S3-WROOM-1-N8 | ENKU_Clock:ESP32-S3-WROOM-1_ENKU
U2 | 1 | BQ24074RGTR | ENKU_Clock:BQ24074_RGT
U3 | 1 | TPS62840DLCR | ENKU_Clock:TPS62840_DLC0008B
U4 | 1 | RV-3028-C7 TA QC | ENKU_Clock:RV-3028-C7 | Micro Crystal commercial grade, -40 to +85C
U5 | 1 | VEML7700-TR | ENKU_Clock:VEML7700 | LOCKED: Vishay VEML7700-TR side-view tape-and-reel. VEML7700-TR1 is not approved; VEML7700-TT is the top-view variant and is not a drop-in mechanical substitute
U6 | 1 | MAX98357AETE+T | ENKU_Clock:MAX98357A_ETE_TQFN16 | EP tied to GND copper and adjacent through-via outside thermal pad; no via-in-pad process required
U7 | 1 | USBLC6-2SC6 | Package_TO_SOT_SMD:SOT-23-6

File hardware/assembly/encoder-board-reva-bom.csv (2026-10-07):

Designator | Qty | Manufacturer | MPN | Description | Footprint | Populate
J1 | 1 | JST | SM05B-GHS-TB(LF)(SN) | GH 1.25mm 5-pin right-angle SMD | JST_GH_SM05B-GHS-TB_1x05-1MP_P1.25mm_Horizontal | YES
SW1 | 1 | ALPS Alpine | EC11E15244G1 | 11mm rotary encoder 30 detents/15 pulses with push switch | RotaryEncoder_Alps_EC11E-Switch_Vertical_H20mm | YES
H1 H2 | 2 |  |  | M2 mounting hole | 2.2mm drill | NO

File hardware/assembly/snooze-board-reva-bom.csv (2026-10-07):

Designator | Qty | Manufacturer | MPN | Description | Footprint | Populate
J1 | 1 | JST | SM03B-GHS-TB(LF)(SN) | GH 1.25mm 3-pin right-angle SMD | JST_GH_SM03B-GHS-TB_1x03-1MP_P1.25mm_Horizontal | YES
SW1 | 1 | C&K | KSC221GLFS | Sealed tactile switch SPST 2N 6.2x6.2mm | KSC221GLFS | YES
H1 H2 | 2 |  |  | M2 mounting hole | 2.2mm drill | NO

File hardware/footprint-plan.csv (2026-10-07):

Reference | Part | Footprint baseline | Status | Notes
U1 | ESP32-S3-WROOM-1-N8 | RF_Module:ESP32-S3-WROOM-1 | LOCK | Respect Espressif antenna keepout and edge placement
U2 | BQ24074RGTR | ENKU_Clock:BQ24074_RGT | LOCK | 3x3mm VQFN-16 0.5mm pitch; EP 1.7x1.7mm
U3 | TPS62840DLCR | ENKU_Clock:TPS62840_DLC0008B | LOCK | Official TI DLC0008B land: 0.6x0.25mm pads; 0.5mm pitch; 1.3mm row spacing
U4 | RV-3028-C7 | ENKU_Clock:RV-3028-C7 | LOCK | Datasheet land pattern: 8 pads 0.50x0.80mm | 0.90mm pitch
U5 | VEML7700-TR | ENKU_Clock:VEML7700 | LOCK | Side-view 6.8x2.35x3.0mm; optical aperture must face enclosure opening
U6 | MAX98357AETE+T | ENKU_Clock:MAX98357A_ETE_TQFN16 | LOCK | ADI TQFN16 3x3mm; 0.5mm pitch; EP 1.23x1.23mm
U7 | USBLC6-2SC6 | Package_TO_SOT_SMD:SOT-23-6 | LOCK | Place directly at USB-C
Q_FL/AUDIO/AUX | AO3400A | Package_TO_SOT_SMD:SOT-23 | LOCK | Common N-MOS footprint
J1 | TYPE-C-31-M-12 | ENKU_Clock:HRO-TYPE-C-31-M-12 | LOCK | Exact local footprint imported and used on Mainboard
J2 | JST-PH battery 3P | Connector_JST:JST_PH_S3B-PH-K_1x03_P2.00mm_Horizontal | VERIFY | Prefer robust through-hole right-angle
J3 | JST-GH encoder 5P | Connector_JST:JST_GH_SM05B-GHS-TB_1x05-1MP_P1.25mm_Horizontal | LOCK | Mainboard + encoder board matching family
J4 | JST-GH Snooze 3P | Connector_JST:JST_GH_SM03B-GHS-TB_1x03-1MP_P1.25mm_Horizontal | LOCK | Mainboard + Snooze board
J5 | GDEY037T03-FL21 24P FPC | ENKU_Clock:Molex_54550_24P_0.5mm | LOCK_GEOMETRY | Molex manufacturer PCB pattern locked; final top-contact tail orientation to confirm on physical display
J6 | Frontlight 6P FPC | ENKU_Clock:Molex_54550_06P_0.5mm | LOCK_GEOMETRY | Molex manufacturer PCB pattern locked; six-conductor electrical order remains sample-gated
J7 | Speaker 2P | Connector_JST:JST_PH_S2B-PH-K_1x02_P2.00mm_Horizontal | VERIFY | Can move to GH if acoustic module supplier prefers
J8 | JST-GH Wake LED 2P | Connector_JST:JST_GH_SM02B-GHS-TB_1x02-1MP_P1.25mm_Horizontal | LOCK | Remote LED board
SW1-ENC | EC11E15244G1 | ENKU_Clock:ALPS_EC11E15244G1 | CUSTOM | Mechanical shaft datum critical
SW1-SNZ | KSC221GLFS | ENKU_Clock:C&K_KSC221GLFS | CUSTOM | Top actuator alignment critical
D_EPD1-3 | MBR0530 | Diode_SMD:D_SOD-123 | VERIFY | Final package depends chosen equivalent/source
Q_EPD | Si1308EDL class | Package_TO_SOT_SMD:SOT-23 | VERIFY | Must satisfy >=30V and low Vgs threshold
L_EPD | 10uH >=1A | Inductor_SMD:L_3.0x3.0mm_H1.5mm | VERIFY | NR3015-class exact part to be BOM-locked
LED1-6 | Nichia 757 2700K | ENKU_Clock:Nichia_757 | CUSTOM | Optical orientation and diffuser centerline
TP* | Test points | TestPoint:TestPoint_Pad_D1.5mm | LOCK | No-pop production access
JDBG1 | Tag-Connect style 10P | ENKU_Clock:TC2050_IDC_NL | VERIFY | No BOM part; pads only

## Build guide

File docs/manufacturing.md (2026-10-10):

# Manufacturing

## Current stage

An earlier ENKU Clock Rev A package has been submitted for prototype DFM / assembly review. The current audited Mainboard source supersedes that upload and must be re-exported / re-uploaded before payment.

The current green release-candidate source **ed9ddd1** (hardware geometry baseline **1c3d2e55**) passed native KiCad validation with:

- 0 hard DRC violations
- 0 unconnected items
- 0 footprint errors in the final production gate
- BOM / CPL reference match on the Mainboard: **78 / 78 references**
- straight-through harness pin maps match between Mainboard and Encoder (5/5), Snooze (3/3), and Wake LED (2/2)

## Board set

| Board | Size | Layers | Thickness |
|---|---:|---:|---:|
| Mainboard | 88 × 48 mm | 4 | 1.6 mm |
| Encoder | 24 × 23 mm | 2 | 1.6 mm |
| Snooze | 26 × 18 mm | 2 | 1.6 mm |
| Wake LED | 78 × 8 mm | 2 | 1.0 mm |

## Mainboard baseline

- FR-4
- ENIG
- 1 oz outer copper
- 1 oz inner copper
- L1: F.Cu
- L2: GND reference
- L3: power / utility distribution
- L4: B.Cu

Rev A does not claim controlled impedance for USB Full-Speed.

## Assembly notes

The first prototype batch is intended for top-side assembly.

Rev A remote-control conditioning is now hardware-defined: 10 kΩ pull-ups on ENC_A / ENC_B / ENC_SW / SNOOZE_SW and 10 nF from SNOOZE_SW to GND. Encoder debounce remains firmware-side.

Functional component substitutions must not be made without review. Critical groups include:

- power-path and regulator ICs
- RTC
- USB protection and connector
- E Ink power / interface components
- service connectors

Exact sourcing constraints and the old PCBWay quotation findings are recorded in `docs/pcbway-sourcing-reva.md`.

The former U6 MAX98357A exposed-pad via-in-pad has been removed. Its exposed pad now connects through solid F.Cu ground to a normal through-via outside the thermal pad, avoiding solder-wicking and special via-fill requirements at U6.

## Manufacturing files

The canonical source of truth is the KiCad data under `hardware/`.

Gerber, drill, placement and release ZIP files should be generated from a validated source revision. Do not manually edit generated fabrication files.

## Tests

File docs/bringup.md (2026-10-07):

# Rev A bring-up checklist

This checklist is for the first assembled ENKU Clock Rev A hardware.

Do not connect the display, speaker, battery and all daughterboards at once on the first power-up. Bring the system up in controlled stages.

## 0. Before power

- [ ] inspect the board for assembly polarity errors
- [ ] inspect USB-C shell and anchors
- [ ] inspect exposed-pad packages for obvious solder bridges
- [ ] verify no conductive debris is present
- [ ] inspect E Ink FPC connector orientation
- [ ] inspect battery connector polarity against the pack
- [ ] check resistance from +3V3 to GND for an obvious short
- [ ] check resistance from VBUS to GND for an obvious short
- [ ] check resistance from BAT+ to GND for an obvious short

## 1. USB-only power

Use a current-limited USB supply if available.

- [ ] connect USB with battery disconnected
- [ ] observe input current
- [ ] verify VBUS path
- [ ] verify SYS_RAW
- [ ] verify +3V3
- [ ] verify EN / CHIP_PU state
- [ ] check regulator and charger temperatures
- [ ] confirm no unexpected heating

Stop immediately if current is abnormal or any IC heats rapidly.

## 2. MCU and USB

- [ ] confirm ESP32-S3 boots
- [ ] verify UART/debug access
- [ ] verify native USB enumeration
- [ ] verify BOOT / reset access
- [ ] load minimal bring-up firmware

## 3. I2C

With minimal firmware:

- [ ] detect RV-3028-C7
- [ ] detect VEML7700
- [ ] verify RTC interrupt line
- [ ] verify ambient-light readings change with illumination

## 4. Battery and charging

Only after USB-only rails are known good:

- [ ] confirm battery connector polarity again
- [ ] connect protected 1S LiPo
- [ ] verify BAT voltage measurement
- [ ] verify charger state indication
- [ ] verify power-path operation
- [ ] verify USB insertion/removal does not reset unexpectedly
- [ ] confirm charging current and thermal behavior
- [ ] verify NTC behavior if populated

## 5. Physical controls

Connect one daughterboard at a time:

### Encoder
- [ ] ENC_A transitions
- [ ] ENC_B transitions
- [ ] direction decoding
- [ ] push switch
- [ ] no false input during wake-light PWM

### Snooze
- [ ] switch transition
- [ ] deep-sleep wake
- [ ] mechanical force does not flex Mainboard

## 6. Audio

- [ ] enable MAX98357A
- [ ] verify I2S clocks
- [ ] play low-level test tone
- [ ] verify speaker polarity / connector
- [ ] check for digital noise coupling into controls

## 7. Wake light

- [ ] connect Wake LED board
- [ ] start at low PWM duty
- [ ] verify all LED branches
- [ ] check LED polarity and temperature
- [ ] sweep PWM
- [ ] check encoder for PWM-induced false transitions
- [ ] inspect diffuser uniformity in enclosure

## 8. Frontlight

Frontlight conductor order must be confirmed against the actual display sample before full-power testing.

- [ ] verify conductor map
- [ ] start with conservative current
- [ ] verify dimming
- [ ] check thermal behavior

## 9. E Ink

Bring up the E Ink power section only after base rails are stable.

- [ ] inspect HV passives and diode orientation
- [ ] verify display FPC pin 1
- [ ] connect display with power removed
- [ ] verify control signals at logic level
- [ ] enable E Ink power sequence
- [ ] measure expected analog/HV rails
- [ ] check switching components for heating
- [ ] perform first controlled refresh
- [ ] verify BUSY behavior
- [ ] verify power-down sequence

## 10. Sleep / wake

- [ ] RTC wake
- [ ] Snooze wake
- [ ] optional encoder-button wake
- [ ] current measurement in sleep
- [ ] wake-light and frontlight off in sleep
- [ ] no unintended back-power through daughterboards

## 11. Mechanical integration

- [ ] rear USB cutout alignment
- [ ] ESP32 antenna volume remains clear
- [ ] E Ink/frontlight FPC bend radius acceptable
- [ ] all harnesses removable without soldering
- [ ] battery replaceable without removing the display
- [ ] speaker replaceable
- [ ] encoder and Snooze boards independently removable

## 12. Rev A result

Record every issue in the Rev A issue log before changing CAD. Fixes that alter production data should become an explicit new revision or documented Rev A ECO.

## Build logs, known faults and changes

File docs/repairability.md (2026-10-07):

# Repairability

Repairability is a core ENKU design requirement.

## Hardware strategy

ENKU Clock separates frequently handled or mechanically constrained parts from the Mainboard:

- Encoder board
- Snooze board
- Wake LED board

These modules are connected rather than permanently integrated into one large PCB.

## Serviceability goals

- screws rather than destructive enclosure closure where practical
- replaceable battery
- documented connectors and pin functions
- visible reference designators where board area permits
- polarity / pin-1 markings on critical parts
- accessible debug and production-test points
- independent replacement of controls and lighting modules

## Documentation

As Rev A is physically validated, this repository will add:

- connector pinout tables
- disassembly sequence
- battery replacement procedure
- daughterboard replacement procedure
- known-good electrical measurements
- bring-up and diagnostic steps

Repair documentation should describe actual validated hardware, not assumptions from CAD alone.

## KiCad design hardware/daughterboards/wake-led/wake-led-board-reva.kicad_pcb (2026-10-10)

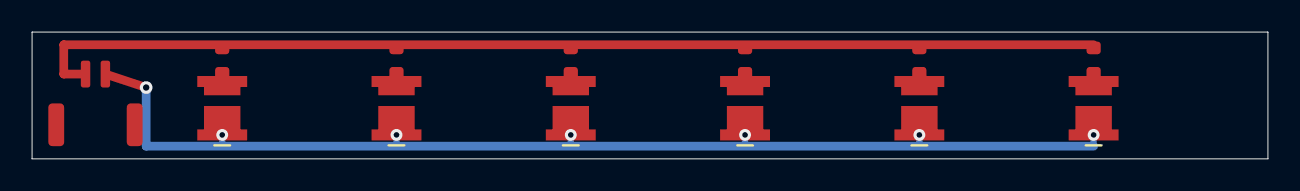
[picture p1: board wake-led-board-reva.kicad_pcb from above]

Board: 2 copper layers, 78.0 x 8.0 mm, 13 parts (0 on the bottom side), 8 nets.

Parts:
D1, D2, D3, D4, D5, D6: NFSW757G-V3 2700K; Nichia_NFSW757G_V3
J1: SM02B-GHS-TB; JST_GH_SM02B-GHS-TB_1x02-1MP_P1.25mm_Horizontal
R1, R2, R3, R4, R5, R6: 56R; R_0603_1608Metric

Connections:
+3V3: J1.1, R1.2, R2.2, R3.2, R4.2, R5.2, R6.2
LED1_A: D1.2, R1.1
LED2_A: D2.2, R2.1
LED3_A: D3.2, R3.1
LED4_A: D4.2, R4.1
LED5_A: D5.2, R5.1
LED6_A: D6.2, R6.1
WAKE_LED_RETURN: D1.1, D2.1, D3.1, D4.1, D5.1, D6.1, J1.2

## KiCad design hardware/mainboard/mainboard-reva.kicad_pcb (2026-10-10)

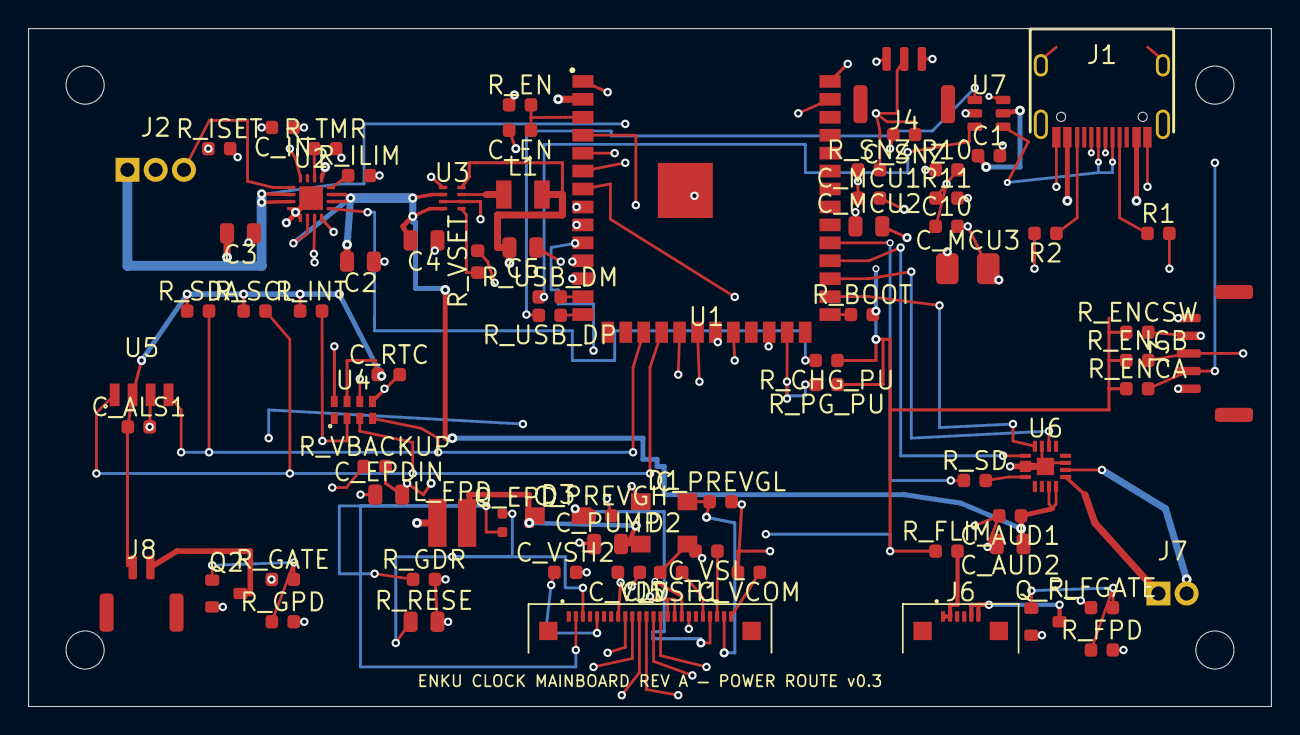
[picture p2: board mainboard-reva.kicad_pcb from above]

Board: 4 copper layers, 88.0 x 48.0 mm, 82 parts (0 on the bottom side), 63 nets.

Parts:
C1: 1uF/10V; C_0603_1608Metric
C2: 4.7uF SYS; C_0805_2012Metric
C3: 4.7uF BAT; C_0805_2012Metric
C4: 4.7uF; C_0805_2012Metric
C5: 10uF; C_0805_2012Metric
C10: 100nF; C_0603_1608Metric
C_ALS1: 100nF; C_0603_1608Metric
C_AUD1: 100nF; C_0603_1608Metric
C_AUD2: 10uF; C_0805_2012Metric
C_EN: 1uF; C_0603_1608Metric
C_EPDIN: 4.7uF/50V; C_0805_2012Metric
C_IN: 1uF/10V; C_0603_1608Metric
C_MCU1: 100nF; C_0603_1608Metric
C_MCU2: 10uF; C_0805_2012Metric
C_MCU3: 100uF low-ESR; C_1210_3225Metric
C_PREVGH: 1uF/50V; C_0603_1608Metric
C_PREVGL: 1uF/50V; C_0603_1608Metric
C_PUMP: 4.7uF/50V; C_0805_2012Metric
C_RTC: 100nF; C_0603_1608Metric
C_SNZ: 10nF; C_0603_1608Metric
C_VCOM: 1uF/50V; C_0603_1608Metric
C_VDD: 1uF/50V; C_0603_1608Metric
C_VSH1, C_VSH2: 1uF/50V; C_0603_1608Metric
C_VSL: 1uF/50V; C_0603_1608Metric
D1, D2, D3: MBR0530; D_SOD-123
H1, H2, H3, H4: MountingHole_2.7mm_M2.5
J1: USB-C; HRO-TYPE-C-31-M-12
J2: BATTERY; JST_PH_S3B-PH-K_1x03_P2.00mm_Horizontal
J3: SM05B-GHS-TB / ENCODER; JST_GH_SM05B-GHS-TB_1x05-1MP_P1.25mm_Horizontal
J4: SM03B-GHS-TB / SNOOZE; JST_GH_SM03B-GHS-TB_1x03-1MP_P1.25mm_Horizontal
J5: Molex 54550-2472 / GDEY037T03-FL21; Molex_54550_24P_0.5mm
J6: Molex 54550-0672 / FL21 frontlight; Molex_54550_6P_0.5mm
J7: SPEAKER; JST_PH_S2B-PH-K_1x02_P2.00mm_Horizontal
J8: SM02B-GHS-TB / WAKE_LED; JST_GH_SM02B-GHS-TB_1x02-1MP_P1.25mm_Horizontal
L1: 2.2uH; L_3.2x2.5mm_H1.2mm
L_EPD: 74438335100 10uH; WE-MAPI_3015_74438335100
Q2: AO3400A / WAKE; SOT-23
Q_EPD: SI1308EDL-T1-GE3; SOT-323_SC-70
Q_FL: AO3400A / FRONTLIGHT; SOT-23
R1: 5.1k CC1; R_0603_1608Metric
R2: 5.1k CC2; R_0603_1608Metric
R10: 1M 1%; R_0603_1608Metric
R11: 330k 1%; R_0603_1608Metric
R_BOOT: 10k; R_0603_1608Metric
R_CHG_PU: 10k; R_0603_1608Metric
R_EN: 10k; R_0603_1608Metric
R_ENCA: 10k; R_0603_1608Metric
R_ENCB: 10k; R_0603_1608Metric
R_ENCSW: 10k; R_0603_1608Metric
R_FGATE: 47R; R_0603_1608Metric
R_FLIM: 10R / tune; R_0603_1608Metric
R_FPD: 100k; R_0603_1608Metric
R_GATE: 47R; R_0603_1608Metric
R_GDR: 10k 1%; R_0603_1608Metric
R_GPD: 100k; R_0603_1608Metric
R_ILIM: 1.18k; R_0603_1608Metric
R_INT: 10k; R_0603_1608Metric
R_ISET: 1.13k; R_0603_1608Metric
R_PG_PU: 10k; R_0603_1608Metric
R_RESE: 0.47R 1%; R_0805_2012Metric
R_SCL: 4.7k; R_0603_1608Metric
R_SD: 2.2k; R_0603_1608Metric
R_SDA: 4.7k; R_0603_1608Metric
R_SNZ: 10k; R_0603_1608Metric
R_TMR: 68k; R_0603_1608Metric
R_USB_DM: 22R; R_0603_1608Metric
R_USB_DP: 22R; R_0603_1608Metric
R_VBACKUP: 10k; R_0603_1608Metric
R_VSET: 267k 1%; R_0603_1608Metric
U1: ESP32-S3-WROOM-1-N8; ESP32-S3-WROOM-1_ENKU
U2: BQ24074RGTR; BQ24074_RGT
U3: TPS62840DLCR; TPS62840_DLC0008B
U4: RV-3028-C7
U5: VEML7700
U6: MAX98357AETE+T; MAX98357A_ETE_TQFN16
U7: USBLC6-2SC6; SOT-23-6

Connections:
+3V3: C5.1, C_ALS1.1, C_EPDIN.1, C_MCU1.1, C_MCU2.1, C_MCU3.1, C_RTC.1, J5.15, J5.16, J8.1, L1.2, L_EPD.1, R_BOOT.2, R_CHG_PU.1, R_EN.1, R_ENCA.1, R_ENCB.1, R_ENCSW.1, R_FLIM.1, R_INT.1, R_PG_PU.1, R_SCL.1, R_SDA.1, R_SNZ.1, U1.2, U3.8, U4.7, U5.2
AMP_SD: R_SD.2, U6.4
AMP_SD_MCU: R_SD.1, U1.31
BAT+: C3.1, J2.1, R10.1, U2.2, U2.3
BAT_ADC: C10.1, R10.2, R11.1, U1.39
BAT_NTC: J2.3, U2.1
BOOT0: R_BOOT.1, U1.27
BUCK_VSET: R_VSET.1, U3.5
CHG_ILIM: R_ILIM.1, U2.12
CHG_ISET: R_ISET.1, U2.16
CHG_STATUS: R_CHG_PU.2, U1.24, U2.9
CHG_TMR: R_TMR.1, U2.14
EN: C_EN.1, R_EN.2, U1.3
ENC_A: J3.2, R_ENCA.2, U1.6
ENC_B: J3.3, R_ENCB.2, U1.7
ENC_SW: J3.4, R_ENCSW.2, U1.12
EPD_BUSY: J5.9, U1.9
EPD_CS: J5.12, U1.21
EPD_DC: J5.11, U1.22
EPD_GDR: J5.2, Q_EPD.2, R_GDR.1
EPD_MOSI: J5.14, U1.20
EPD_PUMP: C_PUMP.1, D1.1
EPD_RESE: J5.3, Q_EPD.1, R_RESE.1
EPD_RST: J5.10, U1.8
EPD_SCK: J5.13, U1.19
EPD_SW: C_PUMP.2, D2.1, D3.1, L_EPD.2, Q_EPD.3
EPD_VCOM: C_VCOM.1, J5.24
EPD_VDD: C_VDD.1, J5.18
EPD_VSH1: C_VSH1.1, J5.20
EPD_VSH2: C_VSH2.1, J5.5
EPD_VSL: C_VSL.1, J5.22
FL_GATE: Q_FL.1, R_FGATE.2, R_FPD.1
FL_LED+: J6.1, J6.2, R_FLIM.2
FL_LED_RETURN: J6.5, J6.6, Q_FL.3
FRONTLIGHT_PWM: R_FGATE.1, U1.11
GND: C1.2, C2.2, C3.2, C4.2, C5.2, C10.2, C_ALS1.2, C_AUD1.2, C_AUD2.2, C_EN.2, C_EPDIN.2, C_IN.2, C_MCU1.2, C_MCU2.2, C_MCU3.2, C_PREVGH.2, C_PREVGL.2, C_RTC.2, C_SNZ.2, C_VCOM.2, C_VDD.2, C_VSH1.2, C_VSH2.2, C_VSL.2, D2.2, J1.A1, J1.A12, J1.S1, J2.2, J3.1, J3.5, J4.1, J4.3, J5.8, J5.17, Q2.2, Q_FL.2, R1.2, R2.2, R11.2, R_FPD.2, R_GDR.2, R_GPD.2, R_ILIM.2, R_ISET.2, R_RESE.2, R_TMR.2, R_VBACKUP.2, R_VSET.2, U1.1, U1.40, U1.41, U2.4, U2.5, U2.8, U2.17, U3.1, U3.3, U3.6, U4.5, U4.8, U5.3, U6.2, U6.3, U6.11, U6.15, U6.17, U7.2
I2C_SCL: R_SCL.2, U1.18, U4.3, U5.1
I2C_SDA: R_SDA.2, U1.17, U4.4, U5.4
I2S_BCLK: U1.28, U6.16
I2S_DOUT: U1.30, U6.1
I2S_LRCLK: U1.29, U6.14
POWER_GOOD: R_PG_PU.2, U1.25, U2.7
PREVGH: C_PREVGH.1, D3.2, J5.21
PREVGL: C_PREVGL.1, D1.2, J5.23
RTC_INT: R_INT.2, U1.4, U4.2
RTC_VBACKUP: R_VBACKUP.1, U4.6
SNOOZE_SW: C_SNZ.1, J4.2, R_SNZ.2, U1.5
SPK+: J7.1, U6.9
SPK-: J7.2, U6.10
SW_3V3: L1.1, U3.7
SYS_RAW: C2.1, C4.1, C_AUD1.1, C_AUD2.1, U2.6, U2.10, U2.11, U3.2, U3.4, U6.7, U6.8
USB_CC1: J1.A5, R1.1
USB_CC2: J1.B5, R2.1
USB_D+: R_USB_DP.1, U7.1
USB_D+_CONN: J1.A6, J1.B6, U7.6
USB_D+_MCU: R_USB_DP.2, U1.14
USB_D-: R_USB_DM.1, U7.3
USB_D-_CONN: J1.A7, J1.B7, U7.4
USB_D-_MCU: R_USB_DM.2, U1.13
VBUS_USB: C1.1, C_IN.1, J1.A4, J1.A9, U2.13, U7.5
WAKE_GATE: Q2.1, R_GATE.2, R_GPD.1
WAKE_LED_PWM: R_GATE.1, U1.10
WAKE_LED_RETURN: J8.2, Q2.3

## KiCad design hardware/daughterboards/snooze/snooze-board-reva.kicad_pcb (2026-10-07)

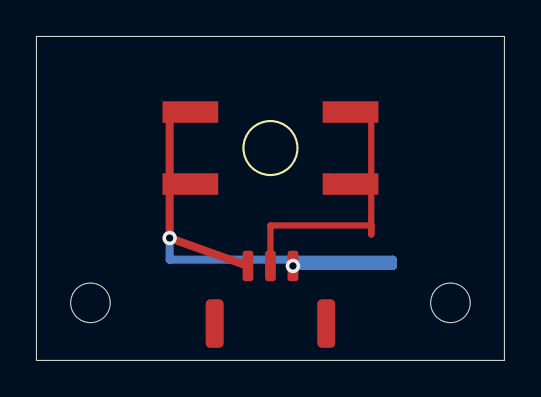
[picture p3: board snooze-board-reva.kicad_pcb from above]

Board: 2 copper layers, 26.0 x 18.0 mm, 4 parts (0 on the bottom side), 2 nets.

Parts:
H1, H2: MountingHole_2.2mm_M2
J1: SM03B-GHS-TB; JST_GH_SM03B-GHS-TB_1x03-1MP_P1.25mm_Horizontal
SW1: KSC221GLFS

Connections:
GND: J1.1, J1.3, SW1.1
SNOOZE_SW: J1.2, SW1.2

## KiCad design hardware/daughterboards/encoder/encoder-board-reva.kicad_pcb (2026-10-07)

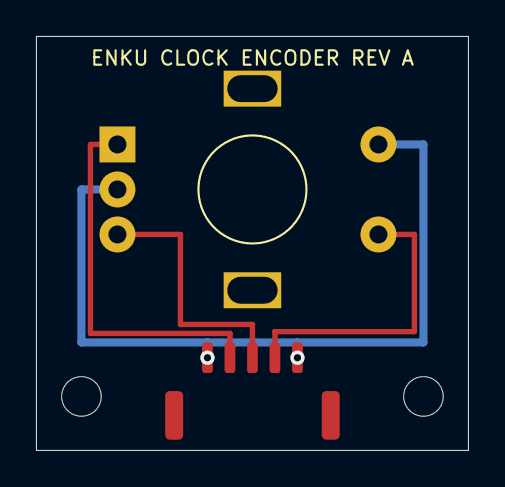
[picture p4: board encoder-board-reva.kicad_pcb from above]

Board: 2 copper layers, 24.0 x 23.0 mm, 4 parts (0 on the bottom side), 4 nets.

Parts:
H1, H2: MountingHole_2.2mm_M2
J1: SM05B-GHS-TB; JST_GH_SM05B-GHS-TB_1x05-1MP_P1.25mm_Horizontal
SW1: EC11E15244G1; RotaryEncoder_Alps_EC11E-Switch_Vertical_H20mm

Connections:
ENC_A: J1.2, SW1.A
ENC_B: J1.3, SW1.B
ENC_SW: J1.4, SW1.S1
GND: J1.1, J1.5, SW1.C, SW1.S2

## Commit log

2026-10-07 Add Rev A PCB sources
    [encoder-board-reva.kicad_pcb, footprint-plan.csv, mainboard-reva.kicad_pcb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]
2026-10-07 Add Rev A assembly data and core schematics
    [ENKU_Clock_RevA.sch, encoder-board-reva-bom.csv, mainboard-reva-bom.csv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]
2026-10-07 Add Rev A schematic sheets
    [audio_light.sch, eink.sch, encoder_board.sch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]
2026-10-07 Add KiCad project libraries
2026-10-07 Complete KiCad footprint library
2026-10-07 Document Rev A external components and harness BOM
2026-10-07 docs: link external component BOM
2026-10-07 docs: lock encoder knob as 3D-printed part
2026-10-07 Add Rev A procurement plan for five prototypes
2026-10-09 fix(wake-led): expose bottom return test via for solder mask layer
    [wake-led-board-reva.kicad_pcb]
2026-10-09 ci: add Wake LED PCBWay release export
2026-10-09 ci: trigger Wake LED release export
    [wake-led-board-reva.kicad_pcb]
2026-10-09 fix(wake-led): add explicit bottom solder mask aperture
    [wake-led-board-reva.kicad_pcb]
2026-10-09 ci: fix Wake LED bottom mask filename check
2026-10-09 ci: accept KiCad lowercase bottom mask filename
2026-10-10 fix(mainboard): align EPD gate and I2C pull-ups with references
    [mainboard-reva.kicad_pcb]
2026-10-10 fix(schematic): use 10k GDR pull-down
    [eink.sch]
2026-10-10 fix(schematic): use 4.7k I2C pull-ups
    [rtc_inputs.sch]
2026-10-10 fix(bom): lock pre-production component values and candidates
    [mainboard-reva-bom.csv]
2026-10-10 fix(schematic): correct SI1308EDL gate/source pin mapping
    [eink.sch]
2026-10-10 fix(mainboard): correct EPD MOSFET pinout and add charger input decoupling
    [mainboard-reva.kicad_pcb]
2026-10-10 fix(bom): add local BQ24074 input bypass
    [mainboard-reva-bom.csv]
2026-10-10 fix(schematic): add local BQ24074 input bypass
    [power_usb.sch]
2026-10-10 fix(mainboard): clear DRC around charger bypass and EPD source route
    [mainboard-reva.kicad_pcb]
2026-10-10 fix(mainboard): move EPD source via clear of switch node
    [mainboard-reva.kicad_pcb]
2026-10-10 fix(mainboard): extend charger safety timer for 3Ah battery
    [mainboard-reva.kicad_pcb]
2026-10-10 fix(schematic): add charge-timer margin for 3Ah pack
    [power_usb.sch]
2026-10-10 fix(bom): set 68k charger safety timer
    [mainboard-reva-bom.csv]
2026-10-10 fix(mainboard): separate EPD gate and source routing
    [mainboard-reva.kicad_pcb]
2026-10-10 fix(mainboard): move EPD pump inner-layer route clear of source via
    [mainboard-reva.kicad_pcb]
2026-10-10 docs: lock FPC connector contact-side production gate
2026-10-10 fix(mainboard): orient USB-C to board edge and reroute port nets
    [mainboard-reva.kicad_pcb]
2026-10-10 fix(footprint): match BQ24074 RGT0016C TI land pattern
2026-10-10 fix(mainboard): use TI RGT0016C land pattern for BQ24074
    [mainboard-reva.kicad_pcb]
2026-10-10 fix(mainboard): clean USB-C breakout lanes and CC placement
    [mainboard-reva.kicad_pcb]
2026-10-10 fix(footprint): center HRO USB-C on official KiCad datum
2026-10-10 fix(mainboard): align USB-C embedded footprint to official datum
    [mainboard-reva.kicad_pcb]
2026-10-10 fix(mainboard): rebuild USB-C breakout with rule-compliant geometry
    [mainboard-reva.kicad_pcb]
2026-10-10 fix(mainboard): separate USB data layers and avoid shell crossing
    [mainboard-reva.kicad_pcb]
2026-10-10 fix(mainboard): clear USB D- tail from local ground return
    [mainboard-reva.kicad_pcb]
2026-10-10 fix(footprint): preserve HRO USB-C local pad clearance
2026-10-10 fix(mainboard): separate USB vias and move VBUS below breakout
    [mainboard-reva.kicad_pcb]
2026-10-10 cleanup(mainboard): remove obsolete USB VBUS stub
    [mainboard-reva.kicad_pcb]
2026-10-10 fix(mainboard): apply TI thermal-pad paste aperture to BQ24074
    [mainboard-reva.kicad_pcb]
2026-10-10 fix(mainboard): finish CC fanout and USB data clearances
    [mainboard-reva.kicad_pcb]
2026-10-10 fix(mainboard): clear final USB CC and differential breakout conflicts
    [mainboard-reva.kicad_pcb]
2026-10-10 fix(mainboard): orient CC1 pulldown for clean fanout
    [mainboard-reva.kicad_pcb]
2026-10-10 ci: export mainboard Gerbers and CPL after strict DRC
2026-10-10 docs: mark current audited mainboard package and PCBWay reupload gate
2026-10-10 fix(mainboard): match EPD inductor land pattern to locked Wurth part
    [mainboard-reva.kicad_pcb]
2026-10-10 feat(footprint): add locked Wurth EPD inductor land pattern
2026-10-10 fix(bom): lock EPD inductor and validate HV capacitor ratings
    [mainboard-reva-bom.csv]
2026-10-10 docs: record exact FL21 reference-circuit audit
2026-10-10 docs: align GPIO and input pull-up notes with Rev A PCB
2026-10-10 fix(mainboard): harden remote control inputs
    [mainboard-reva-bom.csv, mainboard-reva.kicad_pcb]
2026-10-10 fix(mainboard): clear Snooze RC DRC conflicts
    [mainboard-reva.kicad_pcb]
2026-10-10 fix(mainboard): route Snooze around RC ground pad
    [mainboard-reva.kicad_pcb]
2026-10-10 fix(mainboard): relocate Snooze filter below J4
    [mainboard-reva.kicad_pcb]
2026-10-10 fix(hardware): remove audio via-in-pad and correct wake LED polarity marks
    [mainboard-reva-bom.csv, mainboard-reva.kicad_pcb, wake-led-board-reva-bom.csv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]
2026-10-10 fix(bom): lock Rev A sourcing-critical part numbers
    [mainboard-reva-bom.csv]
2026-10-10 fix(bom): approve 54550-0671 for Rev A J6
    [mainboard-reva-bom.csv]
2026-10-10 docs: record J6 prototype sourcing fallback
2026-10-10 fix(bom): lock stocked Rev A wake LED bin
    [wake-led-board-reva-bom.csv]
2026-10-10 ci: rebuild Wake LED release when BOM changes
2026-10-11 ci: build unified Rev A PCBWay submission bundle
